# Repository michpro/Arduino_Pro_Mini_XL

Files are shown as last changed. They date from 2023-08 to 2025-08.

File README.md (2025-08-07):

# **Arduino Pro Mini XL**

- [**Arduino Pro Mini XL**](#arduino-pro-mini-xl)
  - [**Overview**](#overview)
    - [**Features**](#features)
  - [**Schematic diagram**](#schematic-diagram)
  - [**Module visualisation**](#module-visualisation)
  - [**Assembly**](#assembly)
  - [**Production files**](#production-files)
  - [**Software Compatibility**](#software-compatibility)
    - [**Installing MightyCore**](#installing-mightycore)
  - [**Getting Started**](#getting-started)
    - [**Burning the Bootloader**](#burning-the-bootloader)
  - [**Troubleshooting**](#troubleshooting)
  - [**Physical Specifications**](#physical-specifications)
  - [**Reporting bugs**](#reporting-bugs)
  - [**Acknowledgments**](#acknowledgments)
  - [**License**](#license)
  - [**Support**](#support)

---

## **Overview**
The **Arduino Pro Mini XL** is a compact microcontroller board based on the **ATmega1284P**, designed to extend the capabilities of the standard Arduino Pro Mini while retaining its familiar form factor. With increased memory, additional I/O pins, and enhanced features, this board is well-suited for embedded applications requiring greater processing power and connectivity than the ATmega328P-based Arduino Pro Mini can provide. It integrates seamlessly with the Arduino ecosystem, making it accessible to hobbyists, engineers, and developers alike.

### **Features**
* **Microcontroller**: ATmega1284P
* **Flash Memory**: 128KB
* **SRAM**: 16KB
* **EEPROM**: 4KB
* **Digital I/O Pins**: 22
* **Analog Input Pins**: 2
* **Analog Comparator**: 1
* **PWM Channels**: 8
* **UARTs**: 2
* **SPI**: 1
* **I2C**: 1
* **Operating Voltage**: 5V
* **Clock Speed**: 20/16/8MHz
* **Form Factor**: Compatible with Arduino Pro Mini

---

## **Schematic diagram**
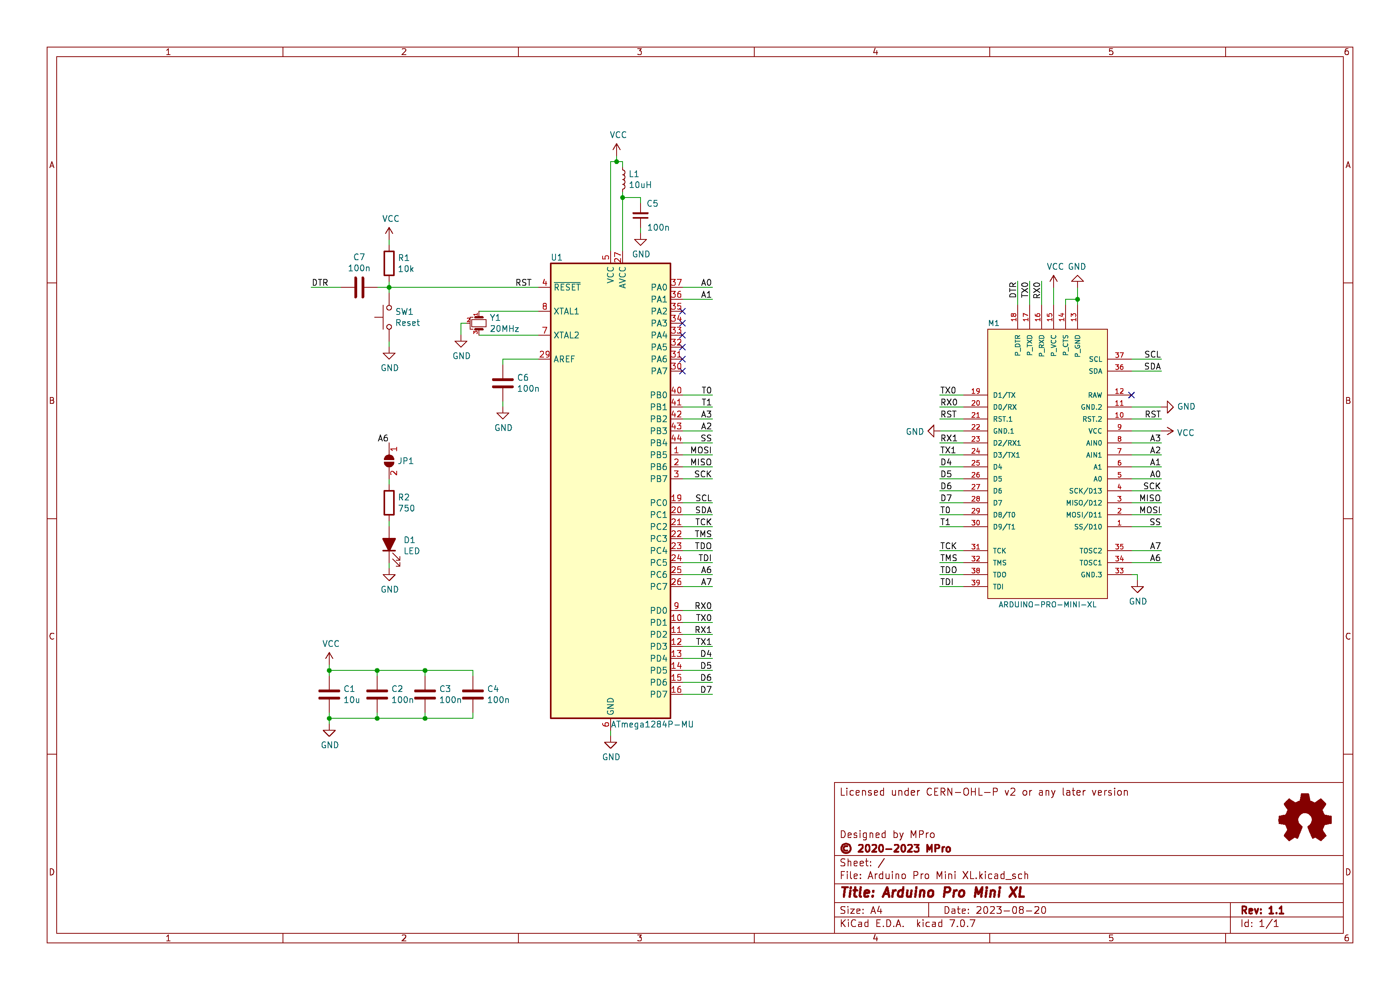
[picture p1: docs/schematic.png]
wiring diagram


## **Module visualisation**
(click on the image to see the 3D model)
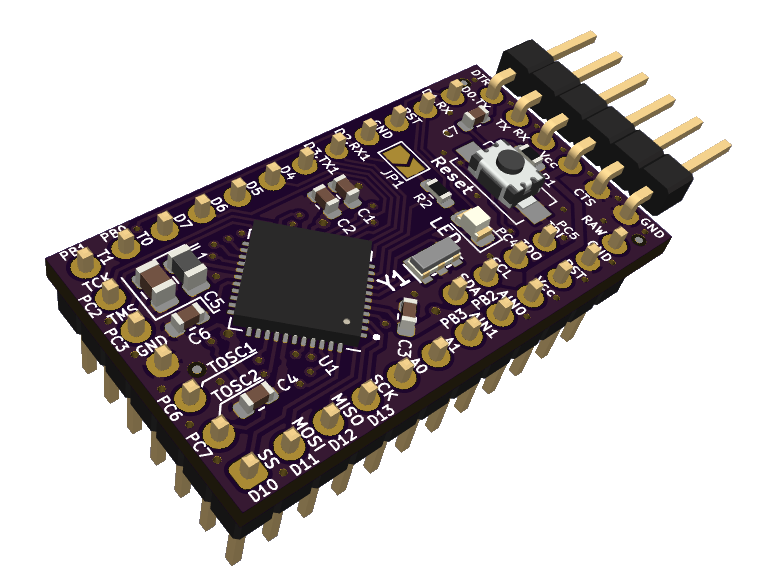
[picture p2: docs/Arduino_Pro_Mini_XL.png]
Arduino Pro Mini XL
<p align="center"></p>

## **Assembly**
[Interactive BOM and placement](https://michpro.github.io/Arduino_Pro_Mini_XL/ibom.html)

## **Production files**
Production files can be found [**here**](./production/).

---

## **Software Compatibility**

The Arduino Pro Mini XL is supported by the Arduino IDE through the [**MightyCore**](https://github.com/MCUdude/MightyCore) board package, which provides board definitions for the ATmega1284P.

### **Installing MightyCore**

To configure the Arduino IDE:

1. Open the Arduino IDE.
2. Navigate to `File` > `Preferences`.
3. Add the following URL to the `Additional Boards Manager URLs` field:  
   ```
   https://mcudude.github.io/MightyCore/package_MCUdude_MightyCore_index.json
   ```
4. Click `OK`.
5. Go to `Tools` > `Board` > `Boards Manager`.
6. Search for "MightyCore" and install the package.

After installation, select **"ATmega1284P"** under `Tools` > `Board`, and configure the variant and clock settings as needed.

## **Getting Started**

1. **Connect the Board**: Attach an FTDI-compatible cable or adapter to the 6-pin programming header.
2. **Configure the IDE**: Select the ATmega1284P board and the appropriate serial port in the Arduino IDE.
3. **Upload a Sketch**: Use a simple sketch, such as "Blink," to test functionality.
   ```cpp
   void setup()
   {
      pinMode(PIN_PC6, OUTPUT); // Onboard LED 
                                // Don't forget to close JP1.
   }

   void loop()
   {
      digitalWrite(PIN_PC6, HIGH);
      delay(1000);
      digitalWrite(PIN_PC6, LOW);
      delay(1000);
   }
   ```
4. **Verify Operation**: Confirm that the onboard LED blinks, indicating successful setup. **Don't forget to close JP1.**

### **Burning the Bootloader**

To burn the bootloader using an ISP programmer:

1. Connect the ISP programmer to the board’s pins.
2. In the Arduino IDE, select the ATmega1284P board and your programmer.
3. Choose `Tools` > `Burn Bootloader`.

Consult the MightyCore documentation for correct fuse settings.

## **Troubleshooting**

- **Upload Failures**: Verify board and port settings; check FTDI connections and drivers.
- **Power Issues**: Ensure input voltage is 5V (VCC); inspect for shorts. *Board has no RAW input*
- **Pin Mapping**: Confirm pin assignments, as they differ from the ATmega328P.

## **Physical Specifications**

- **Dimensions**: Comparable to the Arduino Pro Mini (18.5mm x 33mm).

---

## **Reporting bugs**

[Create an issue on GitHub](https://github.com/michpro/Arduino_Pro_Mini_XL/issues)

---

## **Acknowledgments**

Thanks to the Arduino community and the [**MightyCore**](https://github.com/MCUdude/MightyCore) developers for enabling support for the ATmega1284P.

---

## **License**
Copyright © 2020-2025 Michal Protasowicki

This project is released under CERN Open Hardware Licence Version 2 - Permissive.



---

## **Support**
If You find my projects interesting and You wanted to support my work, You can give me a cup of coffee or a keg of beer :)

&nbsp;&nbsp;&nbsp;&nbsp;&nbsp;&nbsp;&nbsp;&nbsp;&nbsp;&nbsp;

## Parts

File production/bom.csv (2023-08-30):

Designator | Footprint | Quantity | Value | LCSC Part #
C1 | 0603 | 1 | 10u | C19702
C2, C3, C4, C6, C7 | 0603 | 5 | 100n | C14663
C5 | 0805 | 1 | 100n | C49678
D1 | 0805 | 1 | LED | C2297
L1 | 0805 | 1 | 10uH | C1046
R1 | 0603 | 1 | 10k | C25804
R2 | 0603 | 1 | 1k5 | C22843
SW1 | SW_SPST_EVQPE1 | 1 | Reset | C455280
U1 | QFN-44-1EP_7x7mm_P0.5mm_EP5.2x5.2mm | 1 | ATmega1284P-MU | C1337217
Y1 | muRata-resonator_SMD_CSTCExxM00G55-R0 | 1 | 20MHz | C2650766

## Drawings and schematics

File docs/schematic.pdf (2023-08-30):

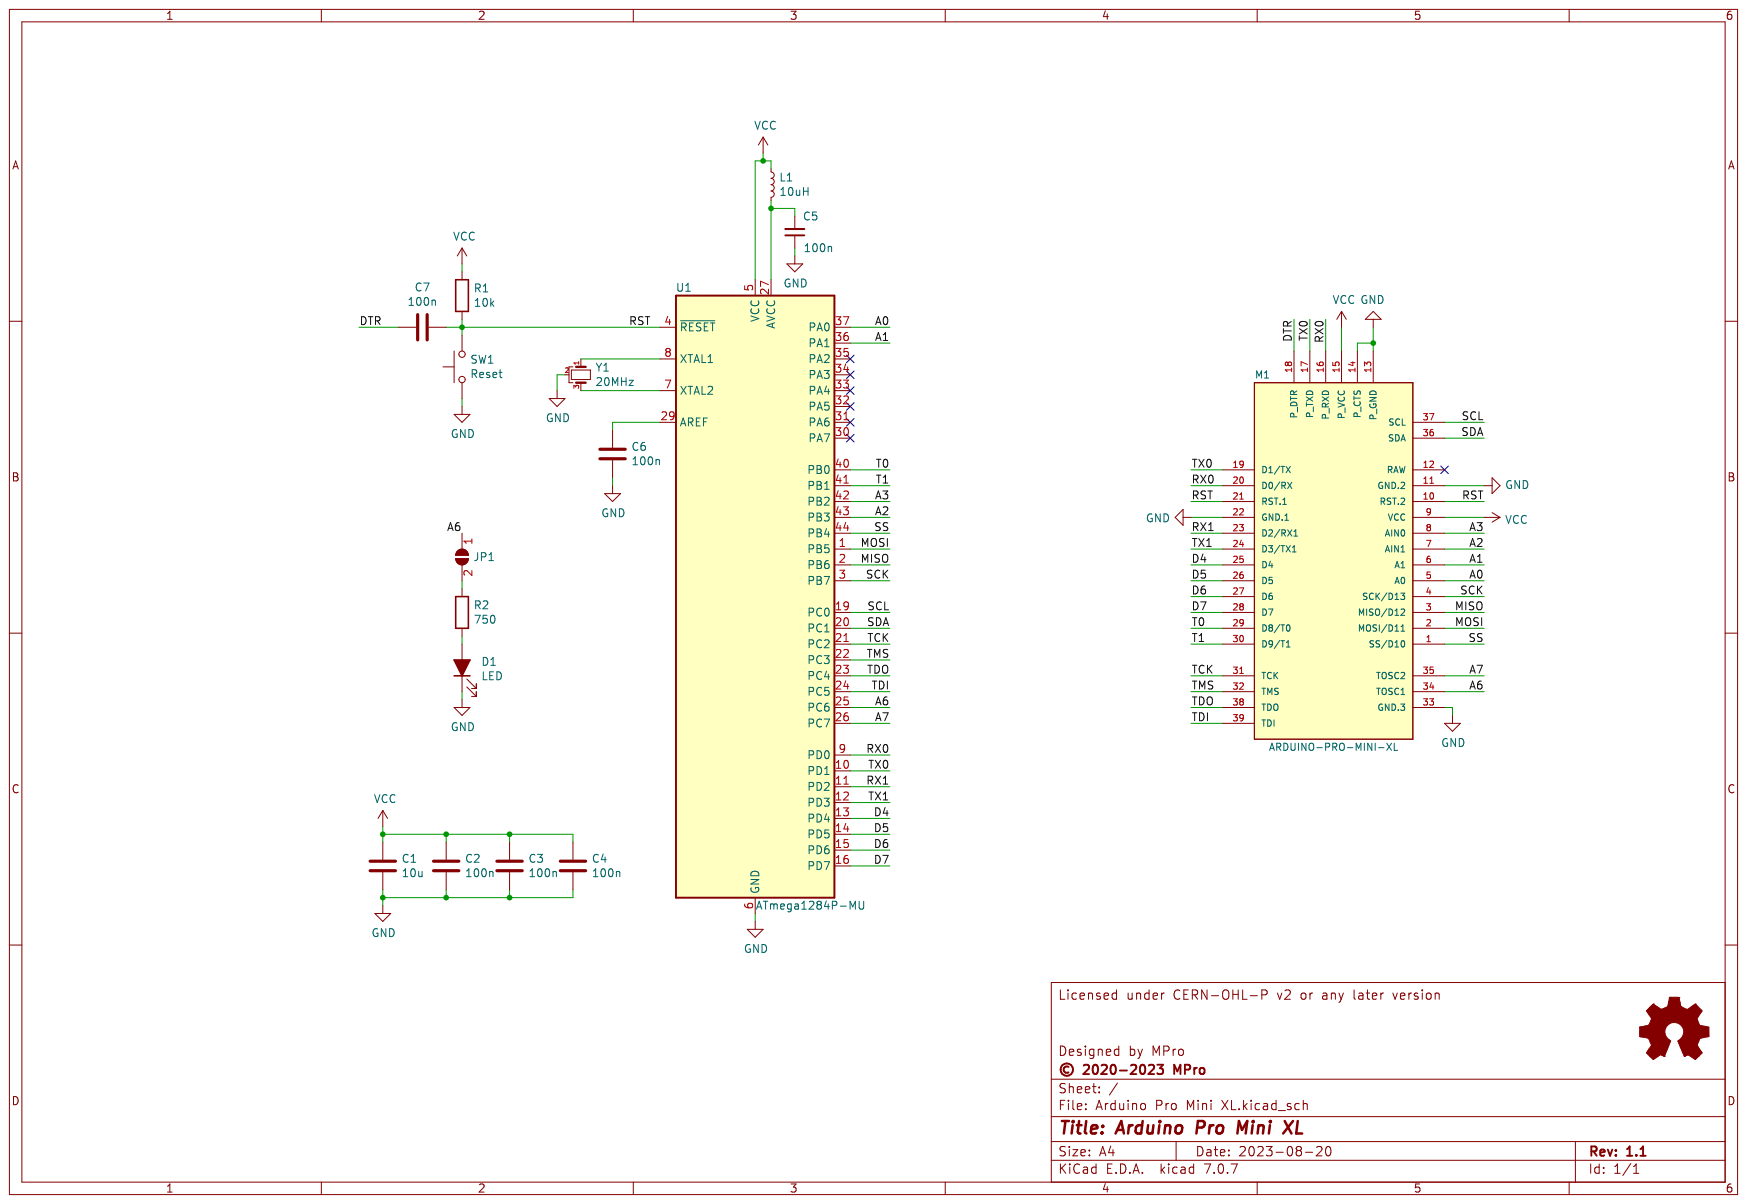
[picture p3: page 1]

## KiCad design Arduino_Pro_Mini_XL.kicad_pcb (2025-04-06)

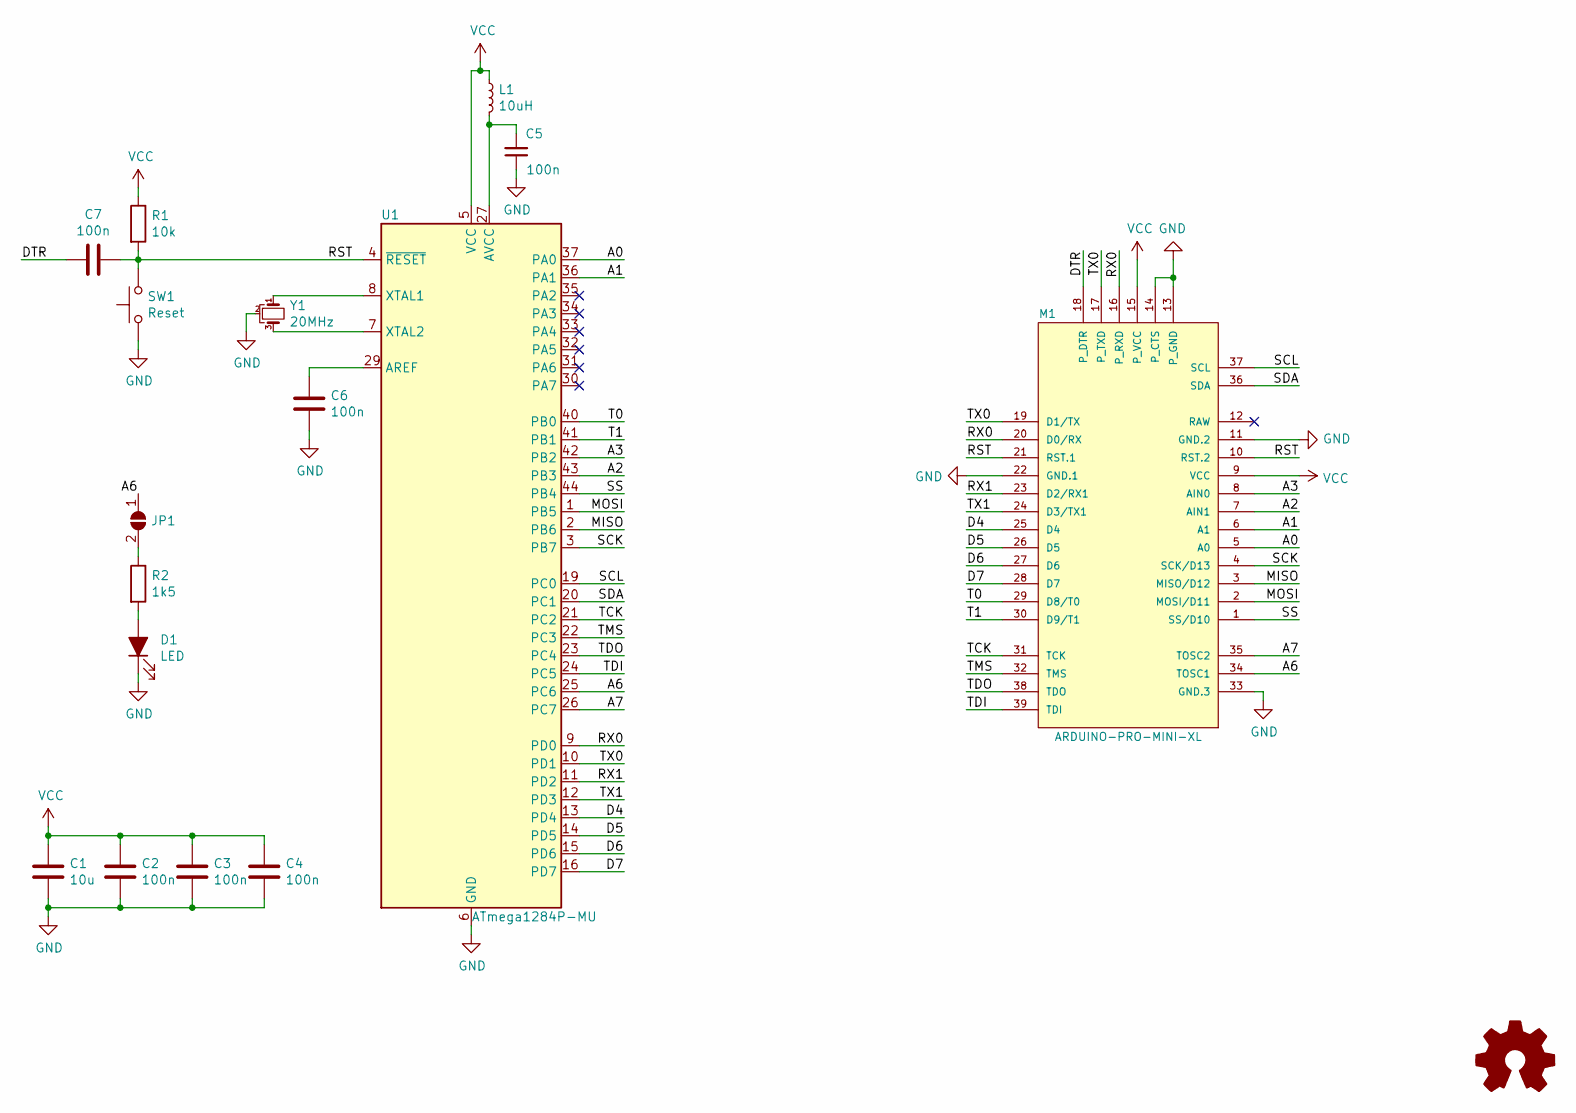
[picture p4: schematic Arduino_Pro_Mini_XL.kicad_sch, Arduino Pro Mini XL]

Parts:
C1: 10u; C_0603_1608Metric; LCSC C19702
C2, C3, C4, C6, C7: 100n; C_0603_1608Metric; LCSC C14663
C5: 100n; C_0805_2012Metric; LCSC C49678
D1: LED; LED_0805_2012Metric; LCSC C2297
JP1: SolderJumper_2_Open; SolderJumper-2_P1.3mm_Open_TrianglePad1.0x1.5mm
L1: 10uH; L_0805_2012Metric; LCSC C1046
LOGO1: Logo_Open_Hardware_Small
M1: ARDUINO-PRO-MINI-XL; diy-modules-ARDUINO-PRO-MINI-XL-BRD
R1: 10k; R_0603_1608Metric; LCSC C25804
R2: 1k5; R_0603_1608Metric; LCSC C22843
SW1: Reset; SW_SPST_EVQPE1; LCSC C455280
U1: ATmega1284P-MU; QFN-44-1EP_7x7mm_P0.5mm_EP5.2x5.2mm; LCSC C1337217
Y1: 20MHz; muRata-resonator_SMD_CSTCExxM00G55-R0; LCSC C2650766

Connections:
/A0: M1.5 (A0), U1.37 (PA0)
/A1: M1.6 (A1), U1.36 (PA1)
/A2: M1.7 (AIN1), U1.43 (PB3)
/A3: M1.8 (AIN0), U1.42 (PB2)
/A6: JP1.1 (A), M1.34 (TOSC1), U1.25 (PC6)
/A7: M1.35 (TOSC2), U1.26 (PC7)
/D4: M1.25 (D4), U1.13 (PD4)
/D5: M1.26 (D5), U1.14 (PD5)
/D6: M1.27 (D6), U1.15 (PD6)
/D7: M1.28 (D7), U1.16 (PD7)
/DTR: C7.2, M1.18 (P_DTR)
/MISO: M1.3 (MISO/D12), U1.2 (PB6)
/MOSI: M1.2 (MOSI/D11), U1.1 (PB5)
/RST: C7.1, M1.10 (RST.2), M1.21 (RST.1), R1.2, SW1.1, U1.4 (~RESET)
/RX0: M1.16 (P_RXD), M1.20 (D0/RX), U1.9 (PD0)
/RX1: M1.23 (D2/RX1), U1.11 (PD2)
/SCK: M1.4 (SCK/D13), U1.3 (PB7)
/SCL: M1.37 (SCL), U1.19 (PC0)
/SDA: M1.36 (SDA), U1.20 (PC1)
/SS: M1.1 (SS/D10), U1.44 (PB4)
/T0: M1.29 (D8/T0), U1.40 (PB0)
/T1: M1.30 (D9/T1), U1.41 (PB1)
/TCK: M1.31 (TCK), U1.21 (PC2)
/TDI: M1.39 (TDI), U1.24 (PC5)
/TDO: M1.38 (TDO), U1.23 (PC4)
/TMS: M1.32 (TMS), U1.22 (PC3)
/TX0: M1.17 (P_TXD), M1.19 (D1/TX), U1.10 (PD1)
/TX1: M1.24 (D3/TX1), U1.12 (PD3)
GND: C1.2, C2.2, C3.2, C4.2, C5.1, C6.2, D1.1 (K), M1.11 (GND.2), M1.13 (P_GND), M1.14 (P_CTS), M1.22 (GND.1), M1.33 (GND.3), SW1.2, U1.6 (GND), U1.18 (GND), U1.28 (GND), U1.39 (GND), U1.45 (GND), Y1.2
unnamed: D1.2 (A), R2.2
unnamed: JP1.2 (B), R2.1
unnamed: C6.1, U1.29 (AREF)
unnamed: C5.2, L1.2, U1.27 (AVCC)
unnamed: U1.8 (XTAL1), Y1.1
unnamed: U1.7 (XTAL2), Y1.3
VCC: C1.1, C2.1, C3.1, C4.1, L1.1, M1.9 (VCC), M1.15 (P_VCC), R1.1, U1.5 (VCC), U1.17 (VCC), U1.38 (VCC)

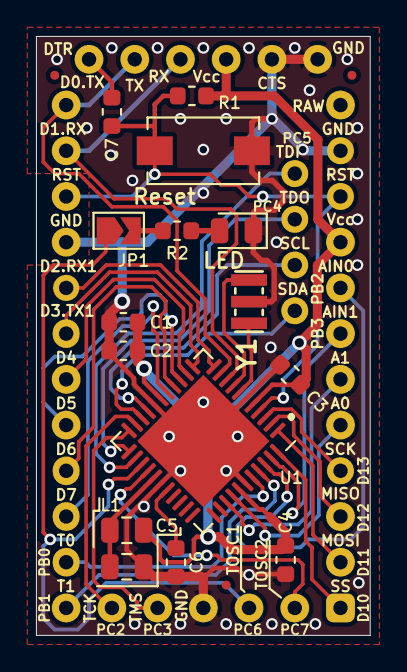
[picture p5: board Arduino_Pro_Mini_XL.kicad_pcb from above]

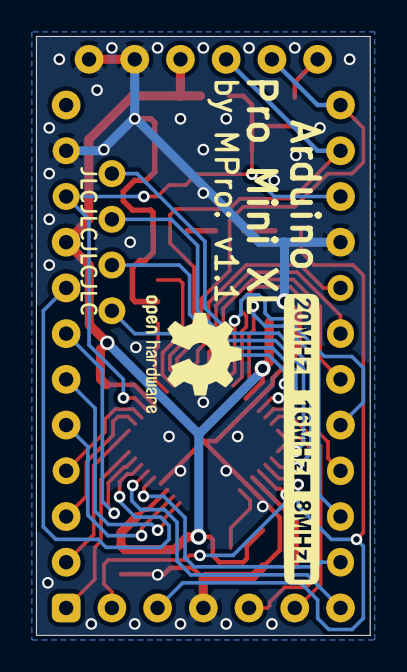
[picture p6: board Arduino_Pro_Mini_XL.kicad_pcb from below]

Board: 2 copper layers, 18.5 x 33.3 mm, 21 parts (2 on the bottom side), 36 nets.

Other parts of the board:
REF1, REF2, REF3: Fiducial_0.5mm_Mask1mm
REF4: OSHW-Logo2_7.3x6mm_SilkScreen
REF5: LOGO; Logo_FREQ_20_16_8MHz

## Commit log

2023-08-30 board version 1.1 updated to KiCad 7.x format
    [Arduino_Pro_Mini_XL.kicad_pcb, Arduino_Pro_Mini_XL.kicad_sch, bom.csv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]
2025-04-06 project files updated to Kicad version 9.0.1
    [Arduino_Pro_Mini_XL.kicad_pcb, Arduino_Pro_Mini_XL.kicad_sch]

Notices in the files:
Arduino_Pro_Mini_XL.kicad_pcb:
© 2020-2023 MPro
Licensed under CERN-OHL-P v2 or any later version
